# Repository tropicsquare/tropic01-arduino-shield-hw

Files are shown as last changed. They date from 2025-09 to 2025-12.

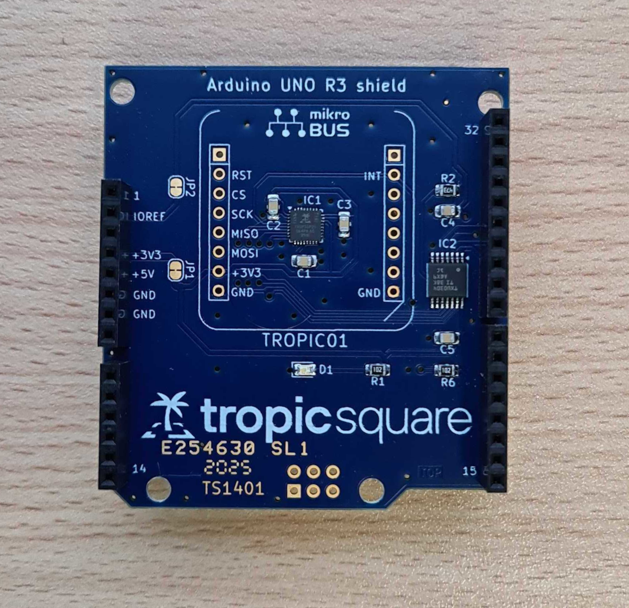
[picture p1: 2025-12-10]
TS1401_design/img/top_assembled.png

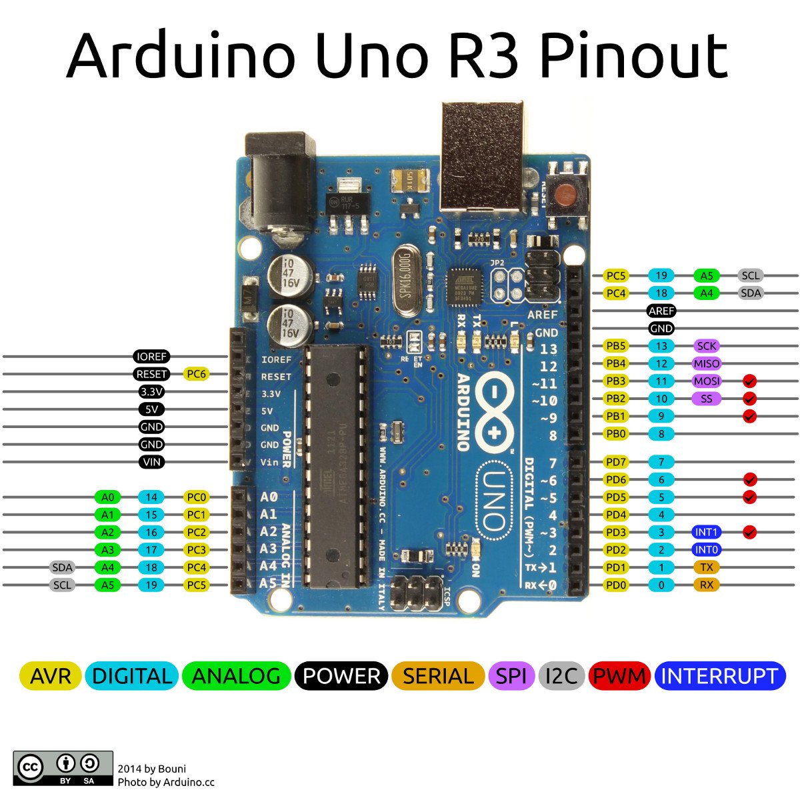
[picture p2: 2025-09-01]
TS1401_design/doc/Arduino_UNO_R3_Pinout.jpg

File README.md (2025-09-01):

# TROPIC01 Arduino Shield

This repository contains the design files for the TROPIC01 development shield, designed for the Arduino form factor. Each folder corresponds to a specific PCB revision.

### About TROPIC01

For more information about the TROPIC01 secure element, please see the official documentation:

*   [TROPIC01 Datasheet](https://github.com/tropicsquare/tropic01/tree/main/doc/datasheet)
*   [TROPIC01 Website](https://www.tropicsquare.com/tropic01)

# Arduino Shield's Versions

Following table shows all versions of distributed shields.

| hw revision | Picture |
|---|---|
| 1401 |  [Top](./TS1401_design/img/top.png) |

# Getting Started

To interact with the TROPIC01 chip on STM32-based systems we provide the [`libtropic-stm32`](https://github.com/tropicsquare/libtropic-stm32) repository, containing integration examples of our platform-independent SDK, [`libtropic`](https://github.com/tropicsquare/libtropic).

 > [!IMPORTANT]
 > Before you start with various examples, we strongly recommend to do two things first:
 > * Read CHIP ID and TROPIC01's firmware versions and **save printed output for future reference**
 > * Update TROPIC01's both internal firmware to latest version.

In [`libtropic-stm32`](https://github.com/tropicsquare/libtropic-stm32) repository, you can find specifice instruction for both operations based on hardware you use.

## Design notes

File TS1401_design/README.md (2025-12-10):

# About

TS14 – TROPIC01 Arduino Shield
A KiCad-based hardware project designed to interface the TROPIC01 device with standard Arduino development boards.

This shield allows easy integration of TROPIC01 into Arduino-based environments for development, testing, and prototyping.
It is intended for internal use and partner evaluation setups, following the Arduino mechanical and electrical interface.

# Project structure

* `*.kicad_pro` - KiCad project file
* `*.kicad_sch` - Schematic file
* `*.kicad_pcb` - PCB layout file
* `./out/` -  Generated Gerber files for PCB manufacturing
* `./bom/` - Bill of materials, including order codes and interactive BOM
* `./img/` - Images (e.g. PCB renders)
* `*_schematics.pdf` - Exported schematic diagrams (latest version)

# Manufacturing instructions:

## Assembly

IC1/CON1: Chose one variant, assembly IC1 or CON1 (not both on one board).
Chose `bom/bom_variant_*`.

Because Arduino boards use female sockets, the shield's connectors must be mounted on the top side 
to allow the pins to extend through to the bottom side for proper connection. \

There are no any special requirements for C and R components.
Where not specified the R tolerance is 5% and C 20%.

## PCB

* Number of cu layers: 2
* Board Thickness: 1.6
* Core: FR4
* Size: 58 x 53mm
* Mask: Blue
* Silkscreen: Yes (TOP only)

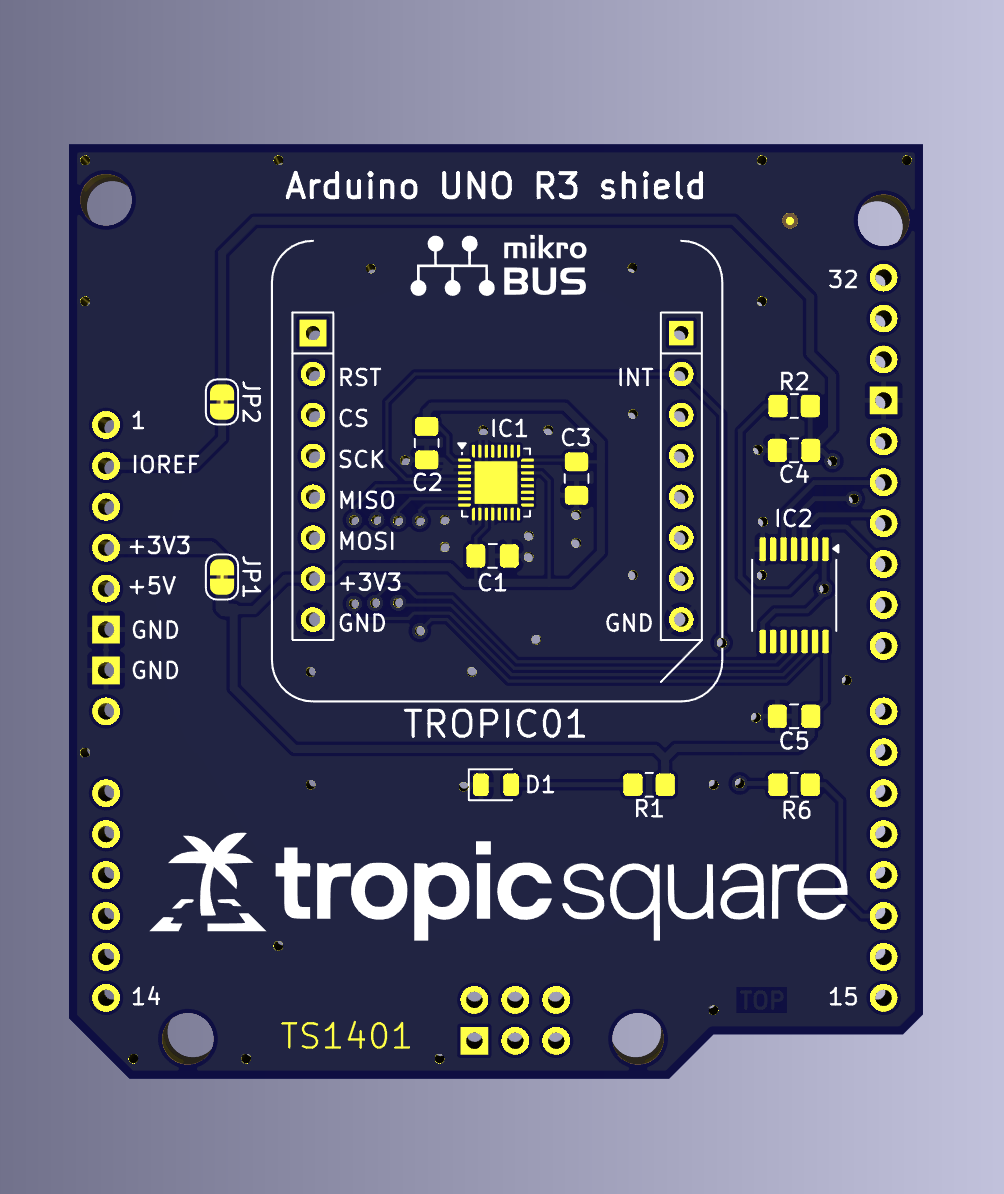
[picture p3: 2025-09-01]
TS1401_design/img/top.png

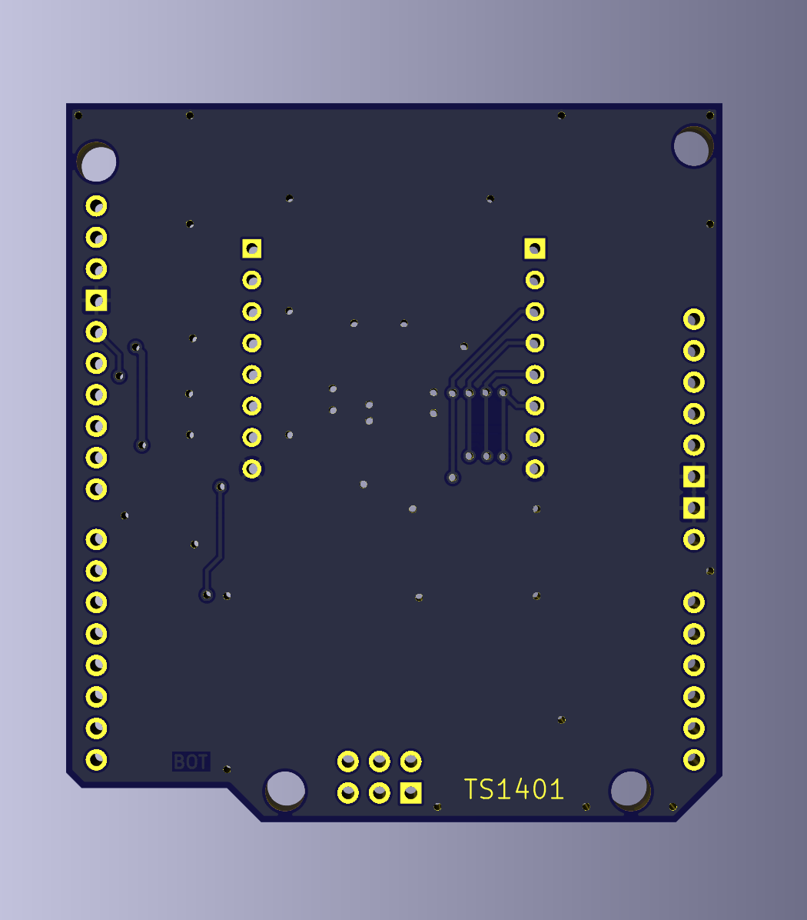
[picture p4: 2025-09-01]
TS1401_design/img/bot.png

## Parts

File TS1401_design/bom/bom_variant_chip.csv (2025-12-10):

Reference | Value | Footprint | Qty | DNP | OC_MOUSER
C1,C2,C3,C4,C5 | 100n | Capacitor_SMD:C_0805_2012Metric_Pad1.18x1.45mm_HandSolder | 5 |  | 187-CL21B104KBFNNNE
CON1 | TROPIC01 | ts_mikrobus:TROPIC01_mikrobus | 1 |  | dont assembly
D1 | LED_G | LED_SMD:LED_0805_2012Metric | 1 |  | 710-150080GS75000
IC1 | TROPIC01_chip | tropic01_chip:QFN-32-1EP_4x4mm_P0.4mm_EP2.65x2.65mm | 1 |  | TR01-C2P-T103
IC2 | TXU0304PWR | Package_SO:TSSOP-14_4.4x5mm_P0.65mm | 1 |  | 595-TXU0304PWR
R1,R6 | 1k | Resistor_SMD:R_0805_2012Metric_Pad1.20x1.40mm_HandSolder | 2 |  | 603-RC0805JR-071KL
R2 | 47k | Resistor_SMD:R_0805_2012Metric_Pad1.20x1.40mm_HandSolder | 1 |  | 603-RC0805JR-0747KL
Shield1 | Arduino_Uno_R3_Shield | shields:Arduino_Uno_R3_Shield | 1 |  | 474-PRT-11417 (set of 4 connectors)

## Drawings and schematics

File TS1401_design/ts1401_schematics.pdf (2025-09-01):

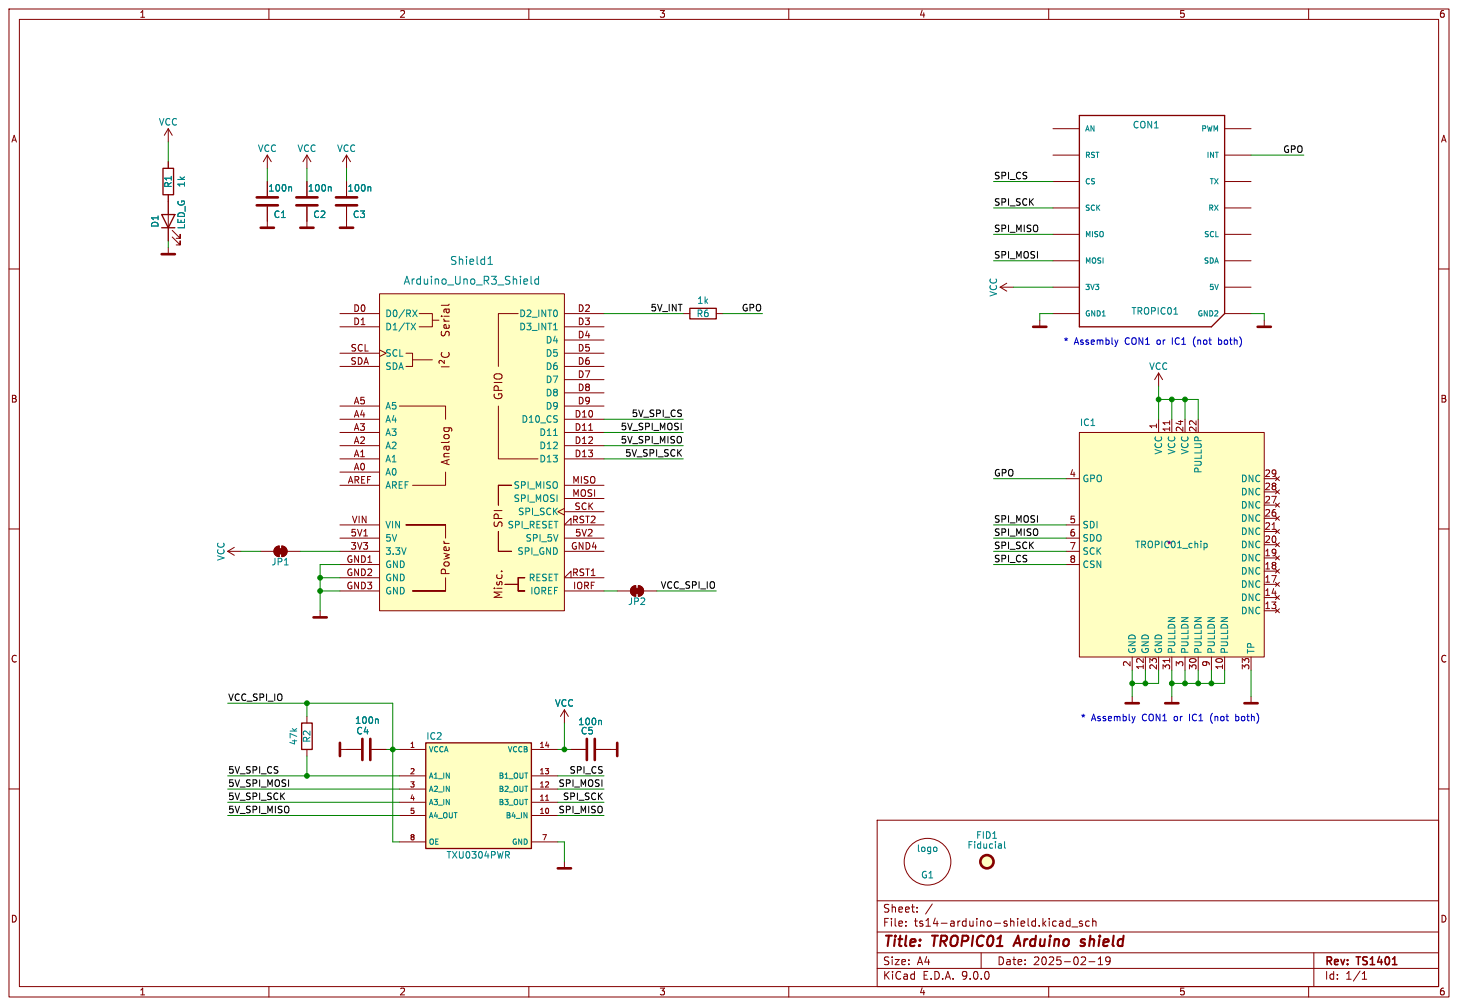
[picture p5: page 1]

File: ts14-arduino-shield.kicad_sch Sheet: /
Id: 1/1 Title: TROPIC01 Arduino shield

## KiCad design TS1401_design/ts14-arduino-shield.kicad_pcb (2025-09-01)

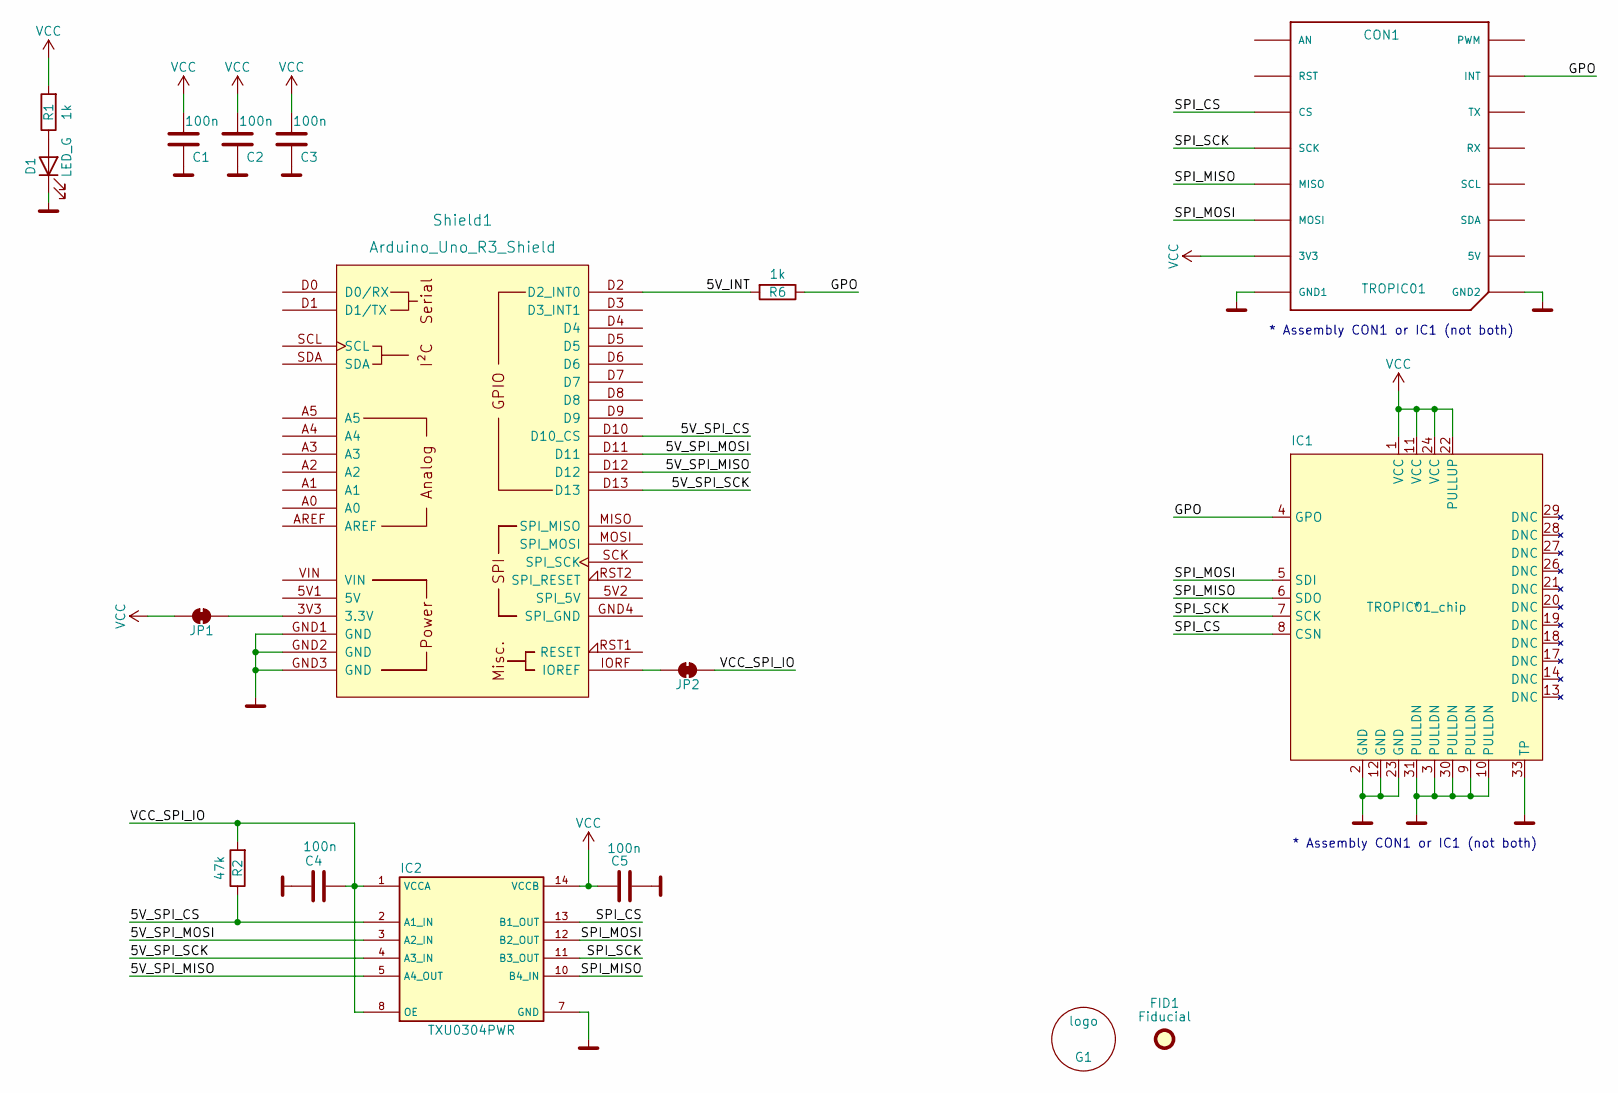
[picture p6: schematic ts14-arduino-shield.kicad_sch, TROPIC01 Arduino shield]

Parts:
C1, C2, C3, C4, C5: 100n; C_0805_2012Metric_Pad1.18x1.45mm_HandSolder
CON1: TROPIC01; TROPIC01_mikrobus
D1: LED_G; LED_0805_2012Metric
FID1: Fiducial; Fiducial_0.5mm_Mask1mm
G1: logo; tropicsquare_logo
IC1: TROPIC01_chip; QFN-32-1EP_4x4mm_P0.4mm_EP2.65x2.65mm
IC2: TXU0304PWR; TSSOP-14_4.4x5mm_P0.65mm
JP1, JP2: SolderJumper_2_Bridged; SolderJumper-2_P1.3mm_Bridged
R1, R6: 1k; R_0805_2012Metric_Pad1.20x1.40mm_HandSolder
R2: 47k; R_0805_2012Metric_Pad1.20x1.40mm_HandSolder
Shield1: Arduino_Uno_R3_Shield

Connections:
/5V_INT: R6.2, Shield1.D2 (D2_INT0)
/5V_SPI_CS: IC2.2 (A1_IN), R2.1, Shield1.D10 (D10_CS)
/5V_SPI_MISO: IC2.5 (A4_OUT), Shield1.D12
/5V_SPI_MOSI: IC2.3 (A2_IN), Shield1.D11
/5V_SPI_SCK: IC2.4 (A3_IN), Shield1.D13
/GPO: CON1.P15 (INT), IC1.4 (GPO), R6.1
/SPI_CS: CON1.P3 (CS), IC1.8 (CSN), IC2.13 (B1_OUT)
/SPI_MISO: CON1.P5 (MISO), IC1.6 (SDO), IC2.10 (B4_IN)
/SPI_MOSI: CON1.P6 (MOSI), IC1.5 (SDI), IC2.12 (B2_OUT)
/SPI_SCK: CON1.P4 (SCK), IC1.7 (SCK), IC2.11 (B3_OUT)
/VCC_SPI_IO: C4.1, IC2.1 (VCCA), IC2.8 (OE), JP2.1 (A), R2.2
GND: C1.1, C2.1, C3.1, C4.2, C5.1, CON1.P8 (GND1), CON1.P9 (GND2), D1.1 (K), IC1.2 (GND), IC1.3 (PULLDN), IC1.9 (PULLDN), IC1.10 (PULLDN), IC1.12 (GND), IC1.23 (GND), IC1.30 (PULLDN), IC1.31 (PULLDN), IC1.33 (TP), IC2.7 (GND), Shield1.GND1 (GND), Shield1.GND2 (GND), Shield1.GND3 (GND)
unnamed: D1.2 (A), R1.1
unnamed: JP1.1 (A), Shield1.3V3 (3.3V)
unnamed: JP2.2 (B), Shield1.IORF (IOREF)
VCC: C1.2, C2.2, C3.2, C5.2, CON1.P7 (3V3), IC1.1 (VCC), IC1.11 (VCC), IC1.22 (PULLUP), IC1.24 (VCC), IC2.14 (VCCB), JP1.2 (B), R1.2

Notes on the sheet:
* Assembly CON1 or IC1 (not both)

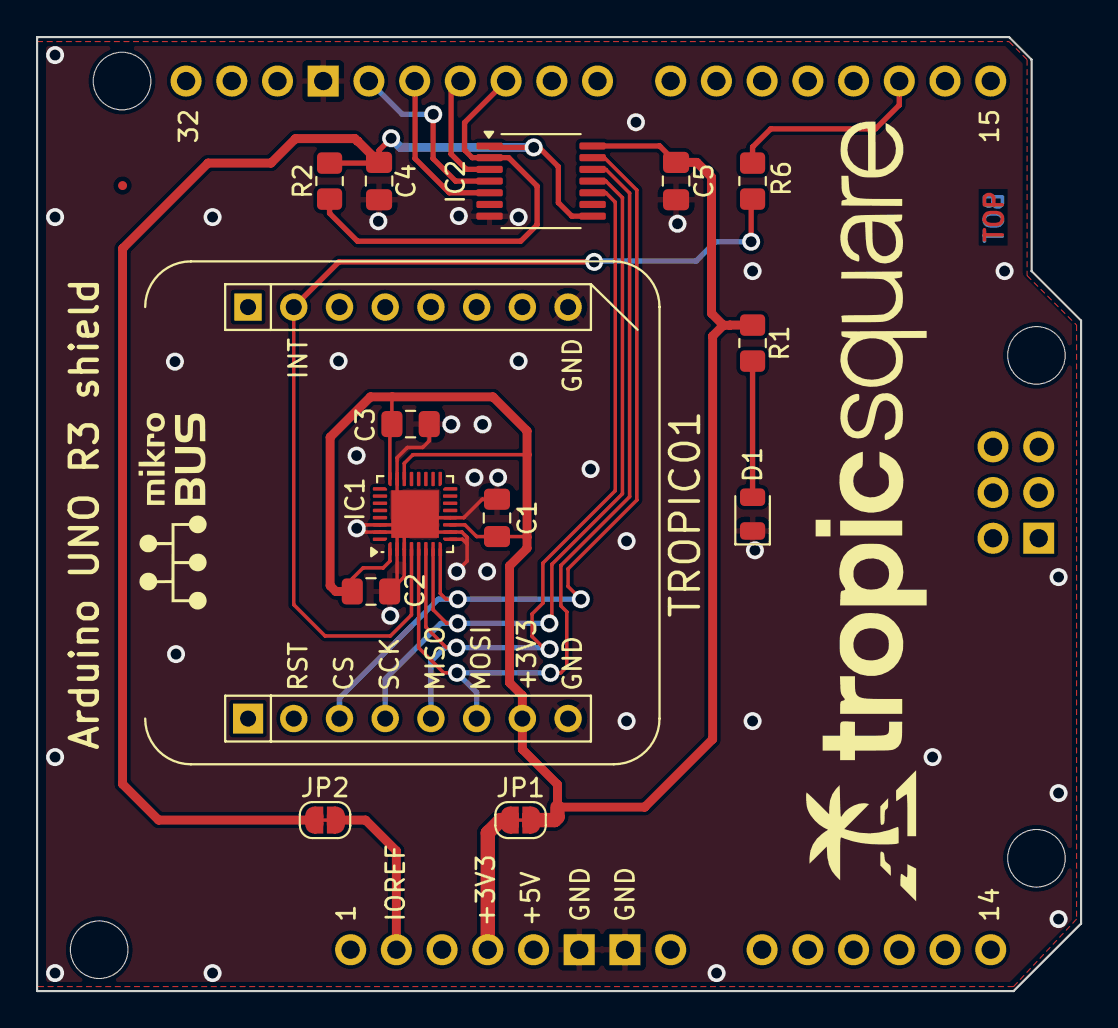
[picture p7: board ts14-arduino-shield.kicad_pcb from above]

Board: 2 copper layers, 58.0 x 53.0 mm, 17 parts (0 on the bottom side), 16 nets.

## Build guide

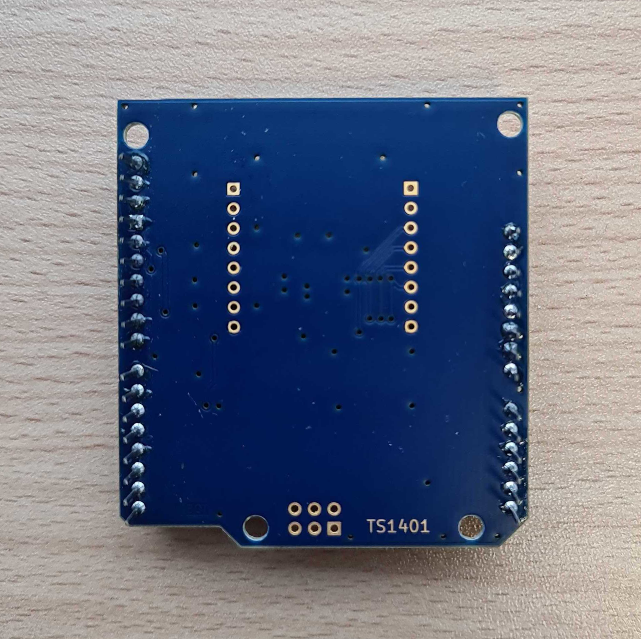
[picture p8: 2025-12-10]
TS1401_design/img/bot_assembled.png

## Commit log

2025-12-10 Fix: Update BOM to fix wrong assembly of MIKROE socket
    [bom_variant_chip.csv, bom_variant_microbus.csv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]
2025-12-10 fix: remove obsolete BOM file
    [bom.csv]
